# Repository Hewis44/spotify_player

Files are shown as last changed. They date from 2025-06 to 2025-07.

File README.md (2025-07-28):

# spotify_player

This is a DIY Spotify Controller built using an ESP32 microcontroller, inspired by the discontinued Spotify Car Thing. The idea came from wanting a simple and elegant way to control music without needing to touch my phone. Since buying the original Car Thing is now super expensive, I decided to make my own version using the components I had and some custom PCB design.



The device uses a 2.4-inch TFT display to show real-time song information like title, artist, and playback progress. It also includes word wrapping, so even long track names are displayed neatly without getting cut off. I’ve added three mechanical switches to handle play/pause, next, and previous track actions, all of which are sent directly to the Spotify Web API over Wi-Fi. To add a fun and futuristic twist, the project includes an NFC reader. Each NFC card can trigger a specific playlist or song, so all you have to do is tap a card, and the vibe changes instantly.



## Update:
---
Motion-Reactive Animation: Dasai Mochi Bot

---

With the latest revision of the PCB, I’ve added an onboard MPU6050 accelerometer and gyroscope module. This opens the door to a brand new feature I call “Dasai Mochi Bot” – a cute, reactive animation engine that responds to motion and song titles.
The MPU6050 detects physical movement too – so if you tilt or shake the device, Mochi responds accordingly (like reacting dizzy or resetting pose). These animations run smoothly on the 2.4" TFT using sprite-based rendering.

Custom esp32:







Custom Case:





## Bill of Materials (BOM)

| Component | Qty | Price (USD) | Price (INR) | Store | Link |
| --- | --- | --- | --- | --- | --- |
| Custom ESP32 PCB Prototype (5 pcs)  | 5 | **\$17.73** | ₹1480 | JLCPCB | — |
| Custom ESP32 PCBA Assembled (2 pcs) | 2 | **\$52.88** | ₹4412 | JLCPCB | — |
| Shipping (Estimated) | 1 | **\$10.24** | ₹854 | JLCPCB | — |
| PN532 NFC Module | 1 | \$3.04 | ₹254 | robocraze.in  | [Buy](https://robocraze.com/products/nfc-near-field-communication-rf-id-v3-module?variant=40193169096857) |
| 2.4" SPI TFT Display | 1 | \$5.54 | ₹463 | robocraze.in  | [Buy](https://robocraze.com/products/2-4in-tft-display-for-uno-board-compatible-with-arduino) |
| Kailh Silver Mechanical Switches | 10  | \$2.99 | ₹250 | cosmicbyte.in | [Buy](https://www.thecosmicbyte.com/product/kailh-mechanical-switches-for-swappable-keyboards-pack-of-10/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) |
| DSA Keycaps | 10  | \$1.80 | ₹150 | amazon.in | [Buy](https://www.amazon.in/MAXBELL-Keycaps-Switches-Mechanical-Keyboard/dp/B09GPQCRC5) |
| NFC Cards | 5 | \$3.00 | ₹260 | amazon.in | [Buy](https://www.amazon.in/Cards-Works-Android-Blank-Printable/dp/B0DH4Q9GY9/) |
| 3D Printed Case | — | — | — | Self-Printed  | Already made |

**🧾 Total Cost:**  
- **USD:** $97.22
- **INR:** ₹8133 (approx.)

FInal assembled and render model:





Spotify integration is done through the Spotify Web API using a library that handles OAuth and token refresh. The ESP32 acts as a remote control and communicates with an existing Spotify session running on a phone, PC, or other authorized device. Once authenticated, the ESP32 can send commands and receive playback data, allowing for full control and status updates on the display.

If you’ve ever wanted your own Spotify control panel, or just enjoy working with NFC, displays, and custom PCBs, this is a great project to try. The code is clean and modular, with all Spotify functions wrapped in a single method that runs in the loop. You can easily modify icons, change the screen layout, or add new NFC cards for more playlists. I’ve added a bill of materials, the .ino sketch, and a build journal to help anyone who wants to replicate or improve on this idea.

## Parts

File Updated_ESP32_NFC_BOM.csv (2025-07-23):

Component | Qty | Price (USD) | Price (INR) | Store | Links
Custom ESP32 PCB Prototype (5 pcs) | 5 | 7 | 585 | JLCPCB | From Screenshot
Custom ESP32 PCBA Assembled (2 pcs) | 2 | 58.05 | 4849 | JLCPCB | From Screenshot
Shipping | 1 | 11.2 | 936 | JLCPCB | From Screenshot
PN532 NFC Module | 1 | 3.04 | 254 | robocraze.in | https://robocraze.com/products/nfc-near-field-communication-rf-id-v3-module?variant=40193169096857
2.4" SPI TFT Display | 1 | 5.54 | 463 | robocraze.in | https://robocraze.com/products/2-4in-tft-display-for-uno-board-compatible-with-arduino
Kailh Silver Mechanical Switches | 10 | 2.99 | 250 | cosmicbyte.in | https://www.thecosmicbyte.com/product/kailh-mechanical-switches-for-swappable-keyboards-pack-of-10/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
DSA Keycaps | 10 | 1.8 | 150 | amazon.in | https://www.amazon.in/MAXBELL-Keycaps-Switches-Mechanical-Keyboard/dp/B09GPQCRC5
NFC Cards | 5 | 3 | 260 | amazon.in | https://www.amazon.in/Cards-Works-Android-Blank-Printable/dp/B0DH4Q9GY9/
3D Printed Case |  |  |  | Self-Printed | Have mine
Total |  | 92.62 | 7747

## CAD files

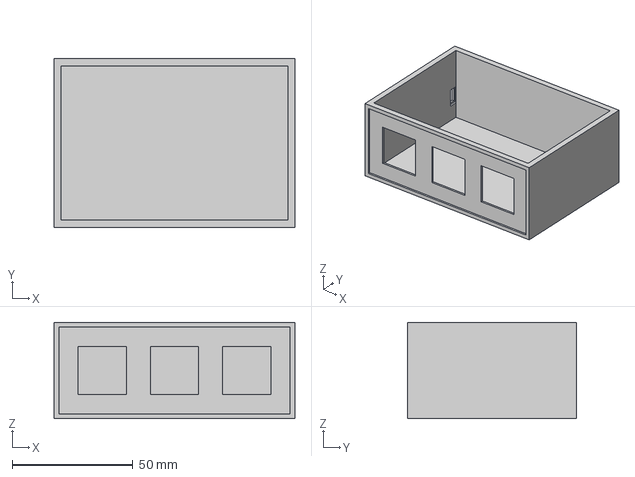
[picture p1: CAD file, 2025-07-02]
Production/Base.step
100.0 x 70.0 x 40.0 mm

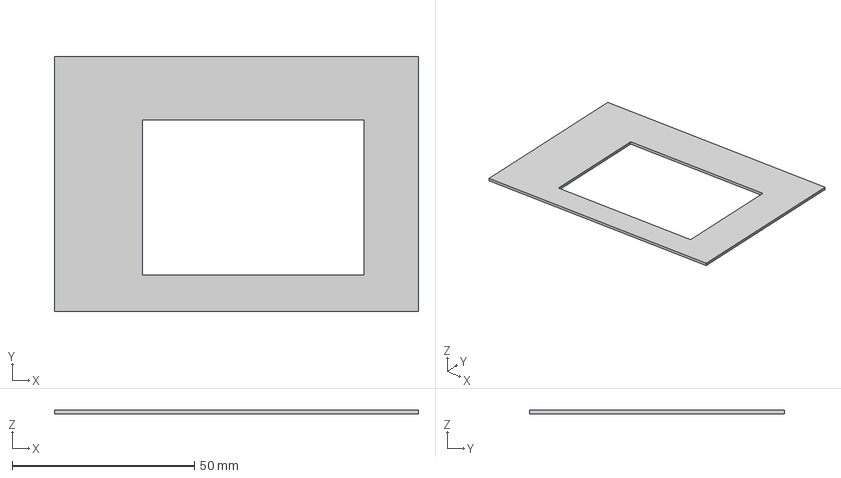
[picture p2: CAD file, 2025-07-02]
Production/lid.step
100.0 x 70.0 x 1 mm

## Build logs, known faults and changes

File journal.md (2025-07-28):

---
Title: "A NFC Spotify player"
Author: "Hewis44"
Description: "Music controller"
created_at: "2025-06-28"
Total time spent: 23 Hours
---

## DAY 1 - 28 JUNE - 9-10 Hours  ( research + schematics + PCB)

So I saw the Spotify Car Thing online and bro, it looked so clean. Minimal, functional, and honestly, just a vibe. But when I checked the price online, it was totally crazy — like ₹15,000 or more. Apparently they discontinued it, and now everyone is just reselling it for insane prices. That’s when I had this lightbulb moment — “Why not build it myself?”  and I’d been wanting to try a custom PCB build with some real-world use. That’s how this whole thing began.
WhatsApp Image 2025-06-17 at 01 03 31_385429e6

i wanted to make smtg like this mann but ik hacklcub will consider this as 4 points project :( so i thought about making it from scratch

Than it flashed in my mind "" HOW ABOUT MAKE AN CUSTOM ESP32 ""
So i started researching on it and found some videos 



FOUND THIS GUY HE IS DA BEST
So as am new to pcb designing i started designing circuit based on his teachings

SO lets start desigining:





This is the brain. ESP32-WROOM module, with its pins all broken out. Capacitors near power pins for decoupling (filtering noise), and few pull-ups/pull-downs if needed for booting. This layout follows Espressif’s hardware design guide, so nothing fancy but solid and tested.



This part is like a traffic cop for power. We’re using a Schottky diode (D1) to make sure power from USB or external supply doesn’t clash. Whichever power is higher gets passed, and the diode prevents backflow. Simple, effective, and safe for the ESP32.



Bro, this is where we plug in our USB-C cable. The connector is USB-C 16-pin type, and the CC pins (Configuration Channel) are pulled down with 5.1kΩ resistors (R1, R2) to let the charger know we're a sink (not a charger). It’s routing the 5V VBUS to our 5V line and also passing D+/D- data lines to the USB-to-Serial IC for programming and debugging. Typical modern setup.



These buttons are the basic “jugaad” for ESP32 dev. One is RESET it just pulls EN low, and the other is BOOT which is actually GPIO0. It’s needed for getting into flash mode. This combo is what allows programming via USB without auto-reset logic, but here we also have that with transistors (next section).



This one is very cool  it uses two NPN BJTs (Q1 & Q2, usually S8050) to control EN and IO0. The USB-to-Serial chip sends DTR and RTS signals, and via some clever resistor network, these BJTs toggle the lines to reset the ESP32 into boot mode automatically during upload. It’s standard in many dev boards, saves you button pressing.



This part is handling all the talking between your PC and the ESP32. The CH340C IC is doing USB to UART conversion. It’s connected to TX, RX, DTR, RTS lines. Since this IC has internal crystal, we don’t need external one less headache. Very budget-friendly and works great for Arduino/ESP stuff.



Since ESP32 needs 3.3V, we’re using AMS1117-3.3 voltage regulator here. It converts the 5V coming from USB to 3.3V safely. Two capacitors (10uF and 100nF usually) on input and output sides to stabilize it. Common setup, works fine but does get a bit hot if current draw is high.



Two LEDs are here for quick debugging. One LED connected with 1k resistor to 3.3V shows that the board is powered (Power LED). Another one is connected to GPIO (maybe GPIO2 or 4) and you can blink it from code. Good to know if your firmware is alive or crashed.



Extra GPIO headers are broken out here for sensors, I2C, SPI, etc. You can connect modules easily with female jumper wires. Makes this custom board usable in multiple projects very modular.

FINAL circuit:



Lets start designing PCB:



THIS WAS SO SATISFYINGGGGGG





I ALSO MADE SOME SILKSCREEN:



( I AM A TRUE AVIATION FAN BTW)

JLCPCB CART:



## DAY 2 - 29 JUNE - 6-8 Hours  ( CASE + CODE)



 I spent almost 6 to 8 hours just sitting and fully focused on finishing the case design and writing the proper code for the Spotify player. Honestly, this day was both frustrating and satisfying. First, I started off by trying to adjust the dimensions properly for the 2.4 inch TFT display, 3 push buttons, 2 18650 batteries, and the NFC module. I made the box in Fusion 360, trying to keep everything tight but also spaced enough so wires don’t mess up later.



The top part of the case was a bit tricky. I had to make those 3 rectangular slots exactly matching the buttons I have, and I didn’t want them to be loose. Below that, I made a big recessed cut for the screen to sit flush inside – I wanted that modern, clean look. In the bottom right, I added a slot to hide the batteries or maybe even fit the ESP32/NFC module depending on wiring.



Once the case design was done and rendered decently, I shifted to coding. The idea was to complete the Spotify logic – like showing the artist, song name, progress bar, and also reacting to button inputs. But the fun part was adding NFC support. That took time to debug, bro. I had to make sure when I tap the tag, it triggers next/previous/play-pause correctly and doesn’t double trigger. So I added delay and string comparison for UID. After testing everything multiple times, it finally worked. That feeling when the song changes with just a card tap – goosebumps only.

So yeah, this day was all about making it feel real. From 3D designing the case like a product, to writing and polishing the full code with NFC magic it really came together.

Ive added evrything in the rep :)

## JUlY 28 - Addon, Code -5 Hours

After finishing the first version of the board, I felt pretty satisfied. But then Logan suggested that I should try adding a feature something that pushes it a bit beyond the basic stuff. And honestly, they were right. I didn’t want this project to just be another tutorial clone. I wanted it to actually do something interesting.





That’s when I thought of the MPU6050. It’s a 6-axis gyroscope and accelerometer, and adding it would give the board motion-sensing capabilities. That idea sounded super fun — like imagine controlling stuff with tilt or tracking movement, all directly from my own custom ESP32 board. So I went back to the schematic, placed the chip, wired up SDA and SCL for I2C, added proper power connections, and re-routed the board to fit everything cleanly. It actually turned out better than I expected, and now the board looks even more packed and powerful.







ALso i wrote some code for some animations based on gyro movements ( i used mpu library )



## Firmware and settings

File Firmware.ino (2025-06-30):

// Made by an Indian kid who loves tech and Spotify :P

#include <ArduinoJson.h>
#include <Adafruit_GFX.h>
#include <Adafruit_ST7735.h>
#include <SPI.h>
#include <Arduino.h>
#include <WiFi.h>
#include <SpotifyEsp32.h>
#include <Wire.h>
#include <Adafruit_PN532.h>

// NFC I2C pins (default for ESP32)
#define SDA_PIN 21
#define SCL_PIN 22
Adafruit_PN532 nfc(SDA_PIN, SCL_PIN);  // This is the NFC module

// Display + Spotify vars
boolean playing;
String lastArtist;
String lastTrackname;
int progressCheck = 0;

// CHANGE ALL THESE TO CONTAIN YOUR INFO! 
char* SSID = "";
const char* PASSWORD = "";
const char* CLIENT_ID = "";
const char* CLIENT_SECRET = "";
const char* REFRESH_TOKEN = "";

// CHANGE BUTTON PINS HERE
#define leftButton 10
#define middleButton 8
#define rightButton 6

// CHANGE SCREEN PINS HERE
#define TFT_CS 5
#define TFT_RST 4
#define TFT_DC 3
#define TFT_SCLK 2
#define TFT_MOSI 1

const unsigned char spotifyLogo[] PROGMEM = {
  0x00, 0x07, 0x80, 0x00,
  0x00, 0x3f, 0xf0, 0x00,
  0x00, 0xff, 0xfc, 0x00,
  0x03, 0xff, 0xff, 0x00,
  0x07, 0xff, 0xff, 0x80,
  0x0f, 0xff, 0xff, 0xc0,
  0x1f, 0xff, 0xff, 0xe0,
  0x1f, 0xff, 0xff, 0xe0,
  0x3f, 0x80, 0x7f, 0xf0,
  0x38, 0x00, 0x03, 0xf0,
  0x78, 0x00, 0x00, 0xf8,
  0x78, 0xff, 0xc0, 0x78,
  0x7f, 0xff, 0xf8, 0x38,
  0xff, 0x80, 0x7f, 0x7c,
  0xfc, 0x00, 0x0f, 0xfc,
  0xfc, 0x00, 0x03, 0xfc,
  0xff, 0xff, 0xe0, 0xfc,
  0x7f, 0xff, 0xf8, 0xf8,
  0x7e, 0x00, 0x3f, 0xf8,
  0x7e, 0x00, 0x0f, 0xf8,
  0x3f, 0xff, 0x83, 0xf0,
  0x3f, 0xff, 0xf3, 0xf0,
  0x1f, 0xff, 0xff, 0xe0,
  0x1f, 0xff, 0xff, 0xe0,
  0x0f, 0xff, 0xff, 0xc0,
  0x07, 0xff, 0xff, 0x80,
  0x03, 0xff, 0xff, 0x00,
  0x00, 0xff, 0xfc, 0x00,
  0x00, 0x3f, 0xf0, 0x00,
  0x00, 0x07, 0x80, 0x00
};

const unsigned char playIcon[] PROGMEM = {
  0x00, 0x00, 0x00,
  0x00, 0x00, 0x00,
  0x00, 0xf0, 0x00,
  0x03, 0xfc, 0x00,
  0x07, 0xff, 0x00,
  0x0f, 0xff, 0x00,
  0x1f, 0xff, 0x80,
  0x1e, 0x67, 0x80,
  0x3e, 0x67, 0xc0,
  0x3e, 0x67, 0xc0,
  0x3e, 0x67, 0xc0,
  0x3e, 0x67, 0xc0,
  0x1e, 0x67, 0x80,
  0x1f, 0xff, 0x80,
  0x0f, 0xff, 0x00,
  0x07, 0xfe, 0x00,
  0x03, 0xfc, 0x00,
  0x00, 0xf0, 0x00,
  0x00, 0x00, 0x00,
  0x00, 0x00, 0x00
};

const unsigned char pauseIcon[] PROGMEM = {
  0x00, 0x00, 0x00,
  0x00, 0x00, 0x00,
  0x00, 0xf0, 0x00,
  0x03, 0xfc, 0x00,
  0x07, 0xff, 0x00,
  0x0f, 0xff, 0x00,
  0x1f, 0xff, 0x80,
  0x1f, 0x3f, 0x80,
  0x3e, 0x0f, 0xc0,
  0x3e, 0x07, 0xc0,
  0x3e, 0x07, 0xc0,
  0x3e, 0x0f, 0xc0,
  0x1f, 0x3f, 0x80,
  0x1f, 0xff, 0x80,
  0x0f, 0xff, 0x00,
  0x07, 0xfe, 0x00,
  0x03, 0xfc, 0x00,
  0x00, 0xf0, 0x00,
  0x00, 0x00, 0x00,
  0x00, 0x00, 0x00
};

const unsigned char prev[] PROGMEM = {
  0x00, 0xf0, 0x00,
  0x03, 0xfc, 0x00,
  0x0c, 0x03, 0x00,
  0x18, 0x01, 0x80,
  0x30, 0x00, 0xc0,
  0x20, 0x00, 0x40,
  0x40, 0x00, 0x20,
  0x42, 0x04, 0x20,
  0xc2, 0x1c, 0x30,
  0xc2, 0x64, 0x30,
  0xc2, 0x64, 0x30,
  0xc2, 0x1c, 0x30,
  0x42, 0x04, 0x20,
  0x40, 0x00, 0x20,
  0x20, 0x00, 0x40,
  0x30, 0x00, 0xc0,
  0x18, 0x01, 0x80,
  0x0c, 0x03, 0x00,
  0x03, 0xfc, 0x00,
  0x00, 0xf0, 0x00
};

const unsigned char next[] PROGMEM = {
  0x00, 0xf0, 0x00,
  0x03, 0xfc, 0x00,
  0x0c, 0x03, 0x00,
  0x18, 0x01, 0x80,
  0x30, 0x00, 0xc0,
  0x20, 0x00, 0x40,
  0x40, 0x00, 0x20,
  0x42, 0x04, 0x20,
  0xc3, 0x84, 0x30,
  0xc2, 0x64, 0x30,
  0xc2, 0x64, 0x30,
  0xc3, 0x84, 0x30,
  0x42, 0x04, 0x20,
  0x40, 0x00, 0x20,
  0x20, 0x00, 0x40,
  0x30, 0x00, 0xc0,
  0x18, 0x01, 0x80,
  0x0c, 0x03, 0x00,
  0x03, 0xfc, 0x00,
  0x00, 0xf0, 0x00
};


boolean playing;
String lastArtist;
String lastTrackname;
int progressCheck = 0;

// Your WiFi + Spotify details, put correct ones or it'll not work :)
char* SSID = "Your_SSID";
const char* PASSWORD = "Your_PASSWORD";
const char* CLIENT_ID = "Your_CLIENT_ID";
const char* CLIENT_SECRET = "Your_CLIENT_SECRET";
const char* REFRESH_TOKEN = "Your_REFRESH_TOKEN";

// Button pins for prev, play/pause, next
#define leftButton 10
#define middleButton 8
#define rightButton 6

// TFT display SPI pins
#define TFT_CS 5
#define TFT_RST 4
#define TFT_DC 3
#define TFT_SCLK 2
#define TFT_MOSI 1

// TFT object banaliya bhai
Adafruit_ST7735 tft = Adafruit_ST7735(TFT_CS, TFT_DC, TFT_MOSI, TFT_SCLK, TFT_RST);
Spotify sp(CLIENT_ID, CLIENT_SECRET);

// Bitmaps (keep your icons like spotifyLogo, playIcon etc. here, skipped for now)
// Add all icons you already have here...

void setup() {
  Serial.begin(115200);

  // Buttons
  pinMode(leftButton, INPUT_PULLUP);
  pinMode(middleButton, INPUT_PULLUP);
  pinMode(rightButton, INPUT_PULLUP);

  // TFT screen init
  tft.initR(INITR_BLACKTAB);
  tft.setRotation(1);
  tft.fillScreen(ST77XX_BLACK);
  tft.setTextSize(1);

  // WiFi connect
  connectToWiFi();

  // Show some info
  tft.setCursor(20, 30); tft.print("SSID: "); tft.print(SSID);
  tft.setCursor(20, 50); tft.print("IP: "); tft.print(WiFi.localIP());

  // Spotify auth bro
  sp.begin();
  while (!sp.is_auth()) {
    sp.handle_client();
  }

  playing = sp.is_playing();

  // Setup NFC
  nfc.begin();
  if (!nfc.getFirmwareVersion()) {
    Serial.println("NFC module not found, check wires!");
    while (1);
  }
  nfc.SAMConfig();
  Serial.println("NFC Ready for scanning");

  // Display icons
  tft.fillScreen(ST77XX_BLACK);
  updatePlayPauseIcon();
  tft.drawBitmap(25, 100, prev, 20, 20, ST77XX_WHITE);
  tft.drawBitmap(115, 100, next, 20, 20, ST77XX_WHITE);
}

void loop() {
  checkInput();
  checkNFC();
  displayTrackInfo();
  if (progressCheck++ > 2) {
    drawProgressBar();
    progressCheck = 0;
  }
}

// Function to connect to WiFi
void connectToWiFi() {
  WiFi.begin(SSID, PASSWORD);
  Serial.print("Connecting to WiFi");
  while (WiFi.status() != WL_CONNECTED) {
    delay(1000);
    Serial.print(".");
  }
  Serial.println("\nWiFi connected");
}

// Check button press and do action
void checkInput() {
  if (digitalRead(middleButton) == LOW) {
    playing = !playing;
    updatePlayPauseIcon();
    if (playing) sp.start_resume_playback();
    else sp.pause_playback();
  }

  if (digitalRead(leftButton) == LOW) {
    sp.previous();
  }
  if (digitalRead(rightButton) == LOW) {
    sp.skip();
  }
}

// Draw Play/Pause icon
void updatePlayPauseIcon() {
  tft.fillRect(70, 100, 20, 20, ST77XX_BLACK);
  if (playing)
    tft.drawBitmap(70, 100, playIcon, 20, 20, ST77XX_WHITE);
  else
    tft.drawBitmap(70, 100, pauseIcon, 20, 20, ST77XX_WHITE);
}

// Show currently playing song and artist
void displayTrackInfo() {
  String artist = sp.current_artist_names();
  String track = sp.current_track_name();

  if (artist != lastArtist || track != lastTrackname) {
    lastArtist = artist;
    lastTrackname = track;

    tft.fillRect(0, 0, 160, 40, ST77XX_BLACK);
    tft.setCursor(5, 5);
    tft.setTextSize(2);
    tft.print(track);

    tft.setCursor(5, 25);
    tft.setTextSize(1);
    tft.print(artist);
  }
}

// Progress bar for song time
void drawProgressBar() {
  StaticJsonDocument<200> filter;
  filter["item"]["duration_ms"] = true;
  filter["progress_ms"] = true;

  response r = sp.current_playback_state(filter);

  int progress = r.reply["progress_ms"];
  int duration = r.reply["item"]["duration_ms"];

  float percent = (float)progress / duration;
  tft.fillRect(0, 124, 160, 4, ST77XX_BLACK);
  tft.fillRect(0, 124, 160 * percent, 4, ST77XX_GREEN);
}

// Check NFC card and trigger command
void checkNFC() {
  uint8_t uid[] = { 0 }; uint8_t uidLength;
  if (nfc.readPassiveTargetID(PN532_MIFARE_ISO14443A, uid, &uidLength)) {
    String uidStr = "";
    for (uint8_t i = 0; i < uidLength; i++) {
      uidStr += String(uid[i], HEX);
    }

    Serial.print("NFC UID: "); Serial.println(uidStr);

    if (uidStr == "aabbccdd") {
      sp.skip();
    } else if (uidStr == "11223344") {
      sp.previous();
    } else if (uidStr == "deadbeef") {
      playing = !playing;
      updatePlayPauseIcon();
      if (playing) sp.start_resume_playback();
      else sp.pause_playback();
    }

    delay(1000); // debounce karo
  }
}

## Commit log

2025-07-01 Update and rename Full_ESP32_Spotify_BOM.csv to BOM.csv
    [BOM.csv]
2025-07-02 Update and rename Basev2.step to Base.step
    [Base.step]
2025-07-02 Update and rename lidv2.step to lid.step
    [lid.step]
2025-07-23 Update and rename Updated_ESP32_NFC_BOM.csv to BOM.csv
    [BOM.csv]
2025-07-28 Update and rename Updated_ESP32_BOM.csv to BOM.csv
    [BOM.csv]
